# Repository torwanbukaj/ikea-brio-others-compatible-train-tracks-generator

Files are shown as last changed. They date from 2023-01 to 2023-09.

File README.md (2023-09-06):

# IKEA Lillabo- & BRIO- & others- compatible train tracks generator

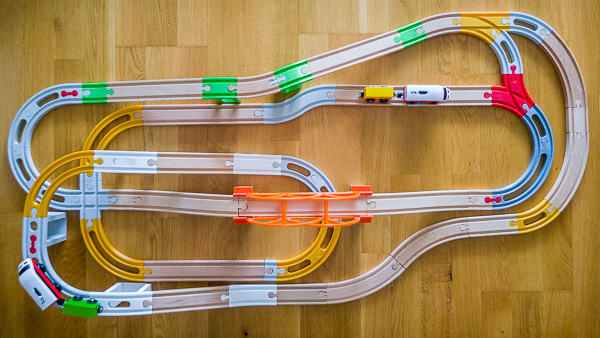
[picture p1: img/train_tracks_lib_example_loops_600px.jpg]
Train tracks loops


This work is licensed under a
[Creative Commons Attribution-NonCommercial-ShareAlike 4.0 International License][cc-by-nc-sa].

# Summary

Read this summary till the end before you print any part generated by this generator!

This repository can be used in two ways:
- just download, slice and 3D print provided STL files,
- generate your own models using provided OpenSCAD file (src/train_tracks_generator.scad), you can easily modify properties of your models as well as change common dimensions used by the generator (track width, height, plug & nest radius etc.).

The generator can so far be used to generate the following types of train tracks:
- short, low profile test track,
- straight tracks,
- arcs (track curves),
- bridges,
- switches,
- intersections,
- "snake" tracks,
- dog-bones (nest-to-nest connection),
- adapters between various train track systems (e.g., IKEA<>BRIO).

Dimensions of the inter-connectors (plugs & nests) are defined based on my own measurements and experiments. They are chosen in a way that connecting a wooden track with a 3D printed one creates a connection which is a little bit tighter than a standard wood-to-wood connection is. Connecting two 3D-printed parts should give a snug and sturdy connection (maintaining a minimal play to ease disconnecting). A play between the parts (wooden vs 3D printed) could be reduced even more but then connecting two 3D-printed parts together would not be possible anymore. Keep it in mind if you decide to play with the configuration parameters.

# Are various train track systems compatible with each other?

It depends on how much force you are willing to apply :) In general, the answer is: NOT, the most popular systems are incompatible. For instance, tracks from IKEA and BRIO do not fit to each other well. The general dimensions of the parts are similar but - for instance - fitting IKEA track plug (shorter) to BRIO track nest (longer) may be impossible without braking or damaging one of the parts. Even if you will manage to connect two incompatible parts, it may be very difficult to disconnect them.
There may be of course exceptions. I found out that J'adore system (sourced from Rossmann) is pretty compatible with BRIO.

Do you posses two or more various systems and want to connect them? With use of my generator, you can easily generate an adapter which will allow to connect two different systems together.

# IMPORTANT - my strong advice - print the tester at first!

Before printing any "bigger" part generated by this generator, I highly recommend to print a tester-track relevant to the system you use:

- file "train_tracks_ikea_tester.stl" (for IKEA Lillabo),
- file "train_tracks_brio_tester.stl" (for BRIO).

This is a short, 20mm-long, low-profile railway track which takes maximum a dozen minutes to print and requires only ~2g of filament. Test the printed part with your train tracks system. It will help you to asses if the dimensions of the parts (including track plug and nest) used by the generator fit dimensions of the tracks you own. If you posses genuine IKEA Lillabo or/and BRIO railway system/s, the generator default dimensions should be fine, nevertheless, when reading various comments for the similar projects on Internet, I found out that in some countries, dimensions of the tracks may differ a little bit from the commonly known. Default dimensions used in this library are tested on tracks available from IKEA (sourced from Germany & Poland), BRIO and J'adore (Rossmann). Please let me know about your test results in the comments and I will add more information to this description if necessary.  

Printed tester does not fit?
I tested multiple combinations of inter-connectors dimensions, so you should not experience any issues but if you do, do not worry, you can easily experiment and customize dimensions used by the generator to fit your system.

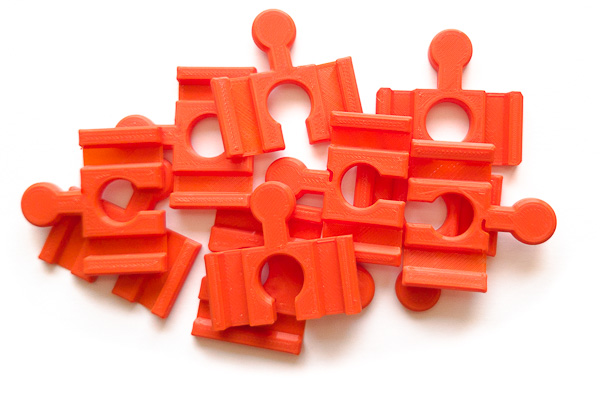
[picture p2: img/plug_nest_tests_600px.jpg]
Plug & nest tests


This is what I call a nest and a plug:

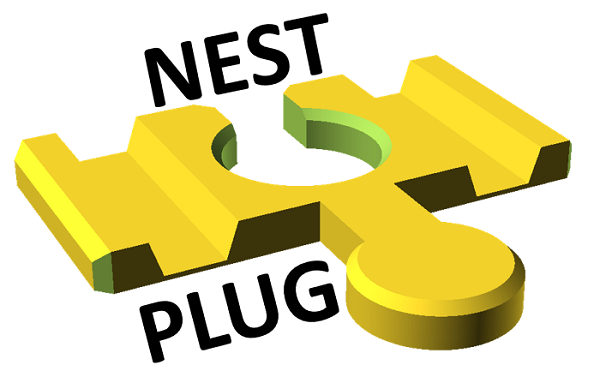
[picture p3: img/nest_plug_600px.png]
Plug & nest


If you want to change dimensions of a plug or a nest, locate these variables in the library and modify according to your needs (example values below are relevant for IKEA Lillabo):

	// Track Plug
	track_plug_radius = 6.25;
	track_plug_radius_ext = 6.5; // for a dog-bone with a springy plug
	track_plug_neck_width = 6.1;
	track_plug_neck_length = 11;
	
	// Track Nest
	track_nest_radius = 6.4;
	rack_nest_neck_width = 6.3;
	track_nest_neck_length = 11;

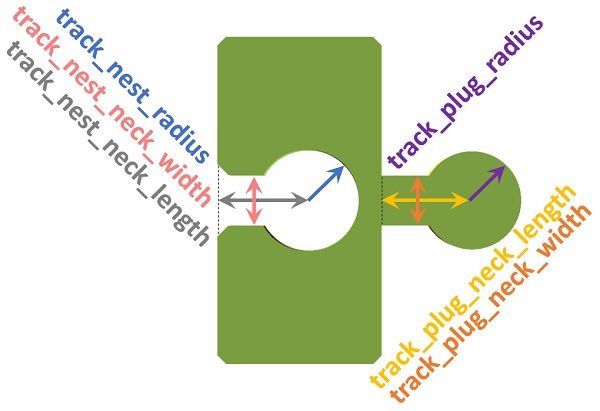
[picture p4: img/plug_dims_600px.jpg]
Plug dimensions


# "We want a bridge!" -> module generate_bridge(); 

This is actually how this story began. We had some IKEA Lillabo and J'adore wooden railway tracks at home but these were only basic parts which were useful for building nothing more than two traditional "2D" loops. One day I heard "We want a bridge!". IKEA is maybe not far away from us but when we want to go there, it's already a kind of trip to organize. And the "bridges" offer is not too impressive in IKEA, and our 3D printer stands in the next room, and there was willingness to improve OpenSCAD skills, so...the project was born.

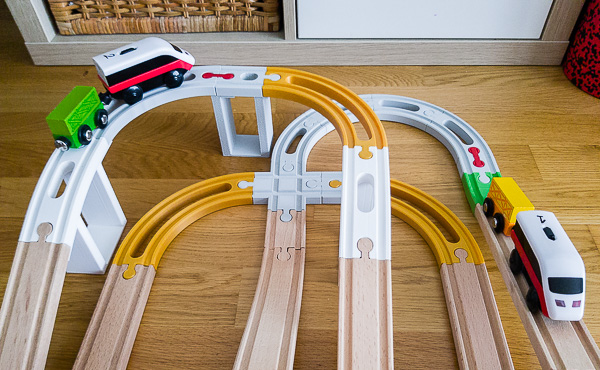
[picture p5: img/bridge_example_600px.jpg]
Example bridge


To build a full bridge, you will need minimum five parts: two "ground" and two "slope" parts,  plus so called a "dog-bone" when you are going to use straight connecting tracks in plug-nest configuration. The ground and slope parts have to be connected by a straight track of your choice. I highly recommend to use one of the standard straight tracks from an original IKEA Lillabo main or expansion set. I think it makes no sense really to print the simplest, commonly available parts.
You can easily extend the total length of the bridge by adding one or more "pillar" track parts.

OpenSCAD module to build a bridge is called "**generate_bridge();**" It takes a few parameters but the most important one is called *what_to_generate". It controls what the module generates. These are the possible values:
- 0 - generates a bridge overview and calculates what will be the height of the bridge,
- 1 - generates only a "ground" part,
- 2 - generates only a "slope" part,
- 3 - generates only a "pillar" part.

This is an example of a bridge overview:

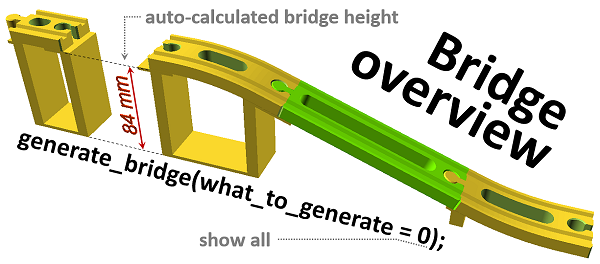
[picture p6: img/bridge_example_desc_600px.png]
Example bridge overview


You can generate a bridge without providing any further parameters. In such a case default values will be used:

	generate_bridge(what_to_generate = 0,
	bridge_angle = 14,
	slope_radius = 100',
	straight_part_l = 205,
	pillar_l = 50,
	cutout = true);

The picture below explains the bridge module parameters:

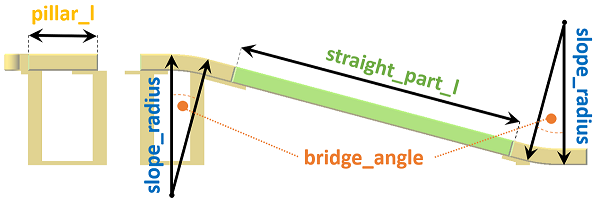
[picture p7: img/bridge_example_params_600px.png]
Bridge parameters


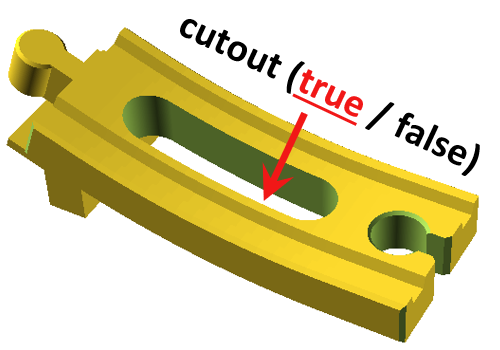
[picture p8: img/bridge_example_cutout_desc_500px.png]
Bridge part cutout description


To speed up printing of the bridge parts and to reduce amount of filament which has to be used for supports, I recommend to slice the parts in the following position (laying on a sidewall):

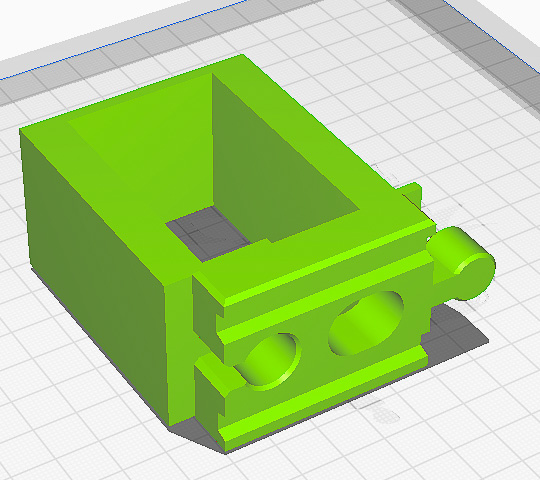
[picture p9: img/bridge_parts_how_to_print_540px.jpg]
Bridge parts - how to print


# Straight railway track -> module track();

Straight railway track is the simplest to generate. Just use **track();** module. You will find explanation of the available parameters on the pictures below:

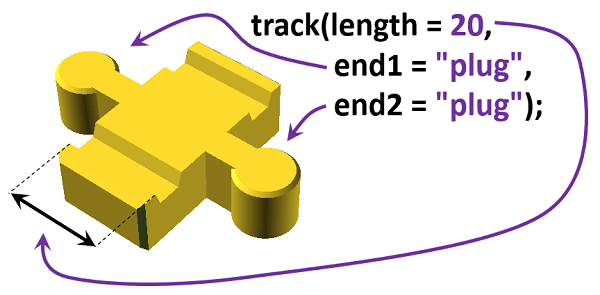
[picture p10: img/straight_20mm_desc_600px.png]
Straight railway track - Example 1

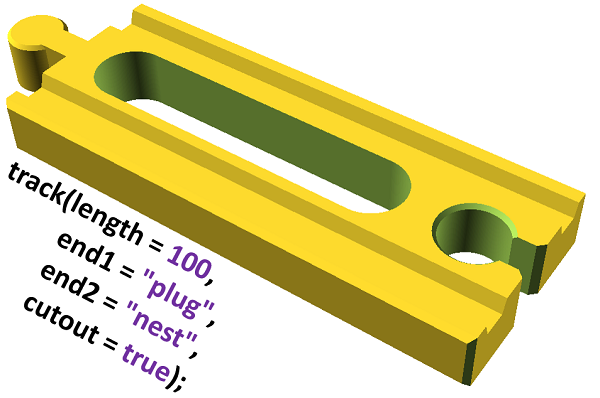
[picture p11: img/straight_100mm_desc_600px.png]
Straight railway track - Example 2


# Arcs -> module track_arc(); 

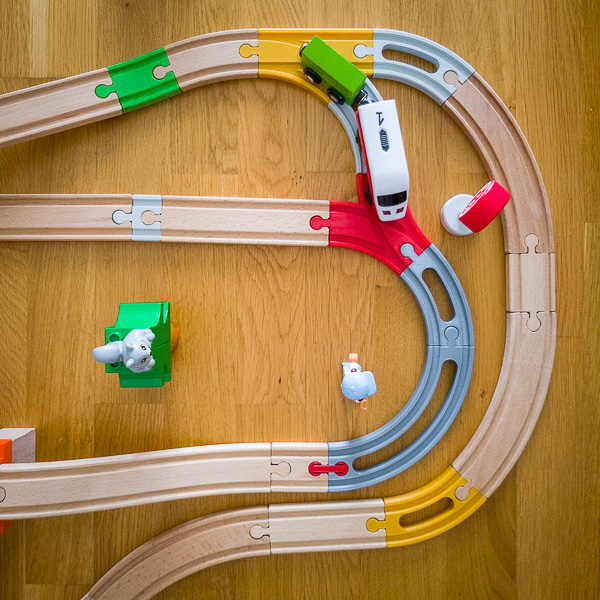
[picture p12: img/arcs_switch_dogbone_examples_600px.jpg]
Arcs examples


To generate an arc, use **track_arc()** module. You can define an ark angle, radius and configuration of its endings (plugs/nests). Positive angles will cause generating an arc which turns to the left and negative angles will force generation of an arc turning right. In addition, you can control if a part will be generated with a material-saving **cutout** or without it. Parameter **both_sides** allows to control if the part will have groves on both sides or only on the top side. This is important if you want to keep the part the most universal (flip it up -side-down and it will turn to the opposite side). 

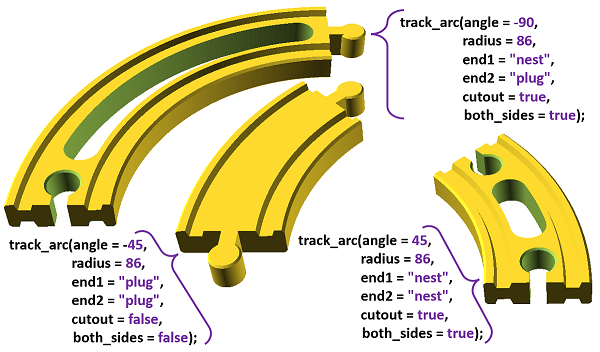
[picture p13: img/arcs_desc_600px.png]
Arc description


# Intersections -> module intersection(); 

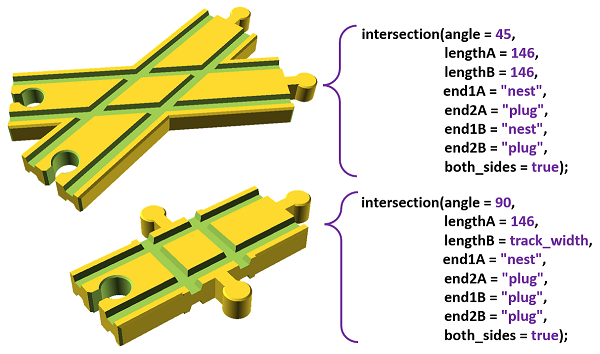
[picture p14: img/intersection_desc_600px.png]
Intersection description


# Switches -> module switch();

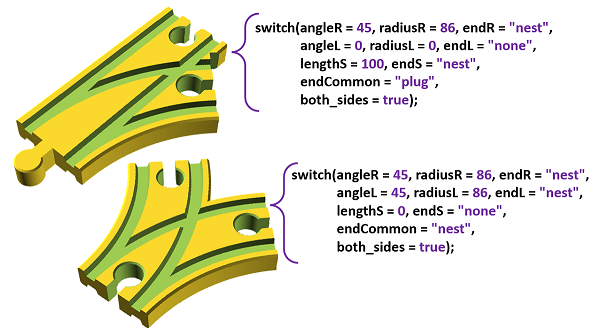
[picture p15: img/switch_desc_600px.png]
Switch description


# "Snake" track -> module snake_track();

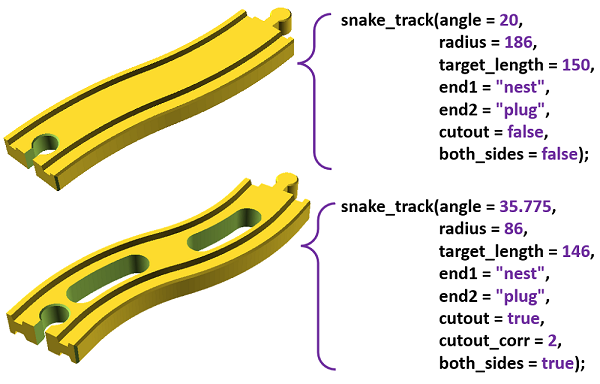
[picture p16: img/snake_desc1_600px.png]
Snake track description 1

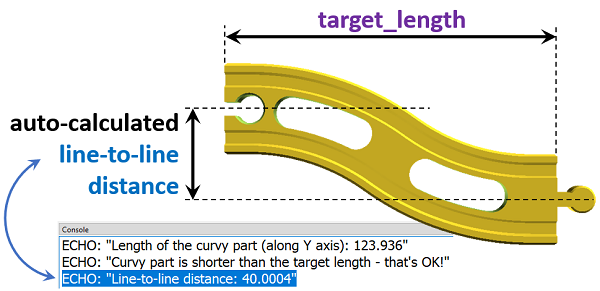
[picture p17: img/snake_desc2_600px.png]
Snake track description 2


# Dog-bone -> module track_dogbone(); 

A dog-bone is a part generated using additional parameter called **track_plug_radius_ext**. It should be always set to a little larger value than standard plug radius. When connecting two track parts facing each other with nests, you are interested in reducing lateral play. This is exactly why the dog-bone has slightly oversized "heads". Deep cutouts allow such plugs to be flexible and tightly fit to slightly "undersized" for them nests.

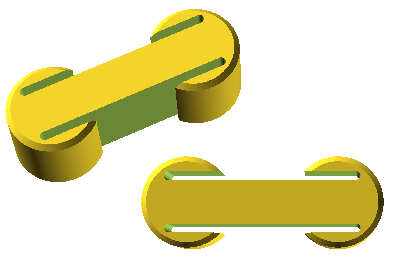
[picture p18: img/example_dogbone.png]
Dog-bone


# Adapters -> module tracks_adapter();

As mentioned in the summary above, some systems are just incompatible with each other (like IKEA and BRIO). This does not mean that you cannot use them together. I guess this incompatibility is just a standard method of locking us - customers - to a specific system. You can easily escape this game played by train tracks manufacturers by using dedicated adapters. Adaptation takes place only in the plug/nest areas (body of a whole adapter is always "common").

Generating an adapter is as easy as calling **tracks_adapter();** module with appropriate parameters (default values in the brackets):

	tracks_adapter(length = 30, nest = "B", plug = "I");

- length - total adapter length (without a plug), I recommend 30mm minimum,
- nest - here you have to define what is the "nest" system,
- plug - here you have to define what is the "plug" system.

So far, dimensions for two plug/nest systems are defined:
- IKEA Lillabo represented by the letter "I",
- BRIO represented by the letter "B".

Below you can find two examples of parts generated to connect IKEA and BRIO systems:

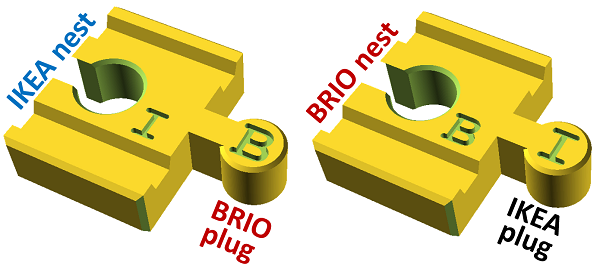
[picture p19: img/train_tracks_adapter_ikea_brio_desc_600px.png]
Adapters description

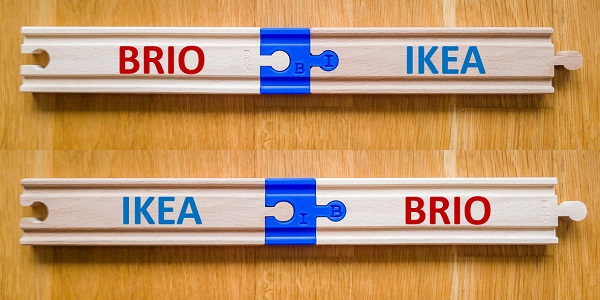
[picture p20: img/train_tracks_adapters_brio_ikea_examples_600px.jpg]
Example adapters


---
Shield: [][cc-by-nc-sa]

This work is licensed under a
[Creative Commons Attribution-NonCommercial-ShareAlike 4.0 International License][cc-by-nc-sa].

[][cc-by-nc-sa]

[cc-by-nc-sa]: http://creativecommons.org/licenses/by-nc-sa/4.0/
[cc-by-nc-sa-image]: https://licensebuttons.net/l/by-nc-sa/4.0/88x31.png
[cc-by-nc-sa-shield]: https://img.shields.io/badge/License-CC%20BY--NC--SA%204.0-lightgrey.svg

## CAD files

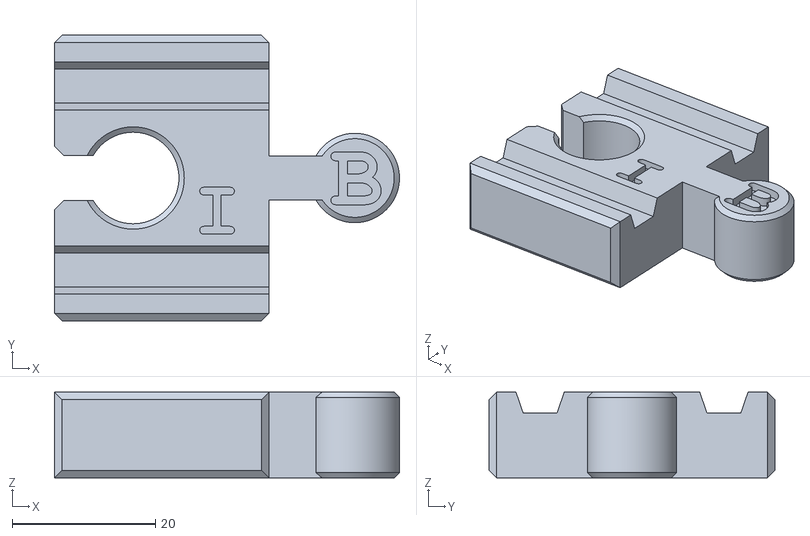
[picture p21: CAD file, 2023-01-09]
pre-generated_parts_stl/adapters/train_tracks_adapter_30mm_ikea-nest_brio-plug.stl
48.2 x 40.0 x 12.0

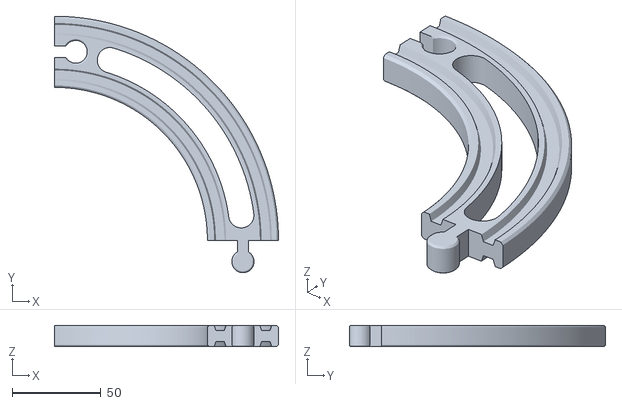
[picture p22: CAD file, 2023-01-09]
pre-generated_parts_stl/brio/train_tracks_brio_arc90deg_r86_b_NP.stl
126.0 x 144.2 x 12.0

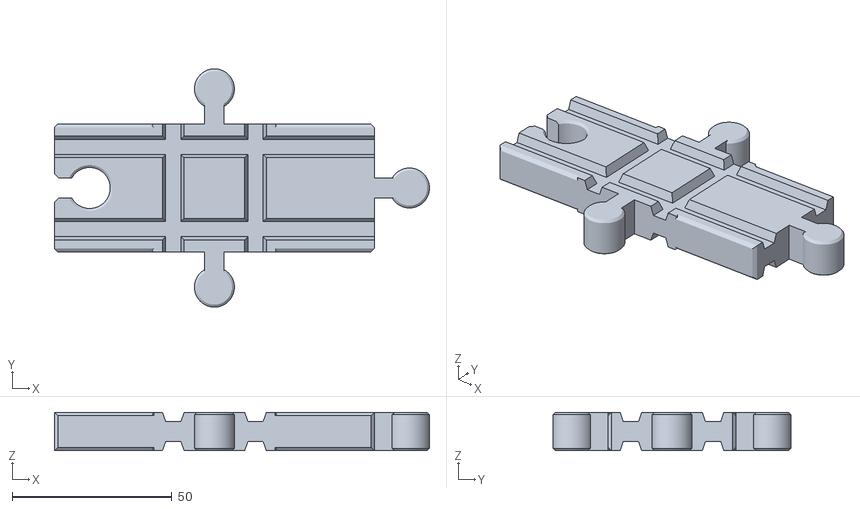
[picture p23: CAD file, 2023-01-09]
pre-generated_parts_stl/ikea/train_tracks_ikea_lillabo_intersect_90deg_100mmNP_40mmPP_b.stl
117.2 x 74.5 x 12.0

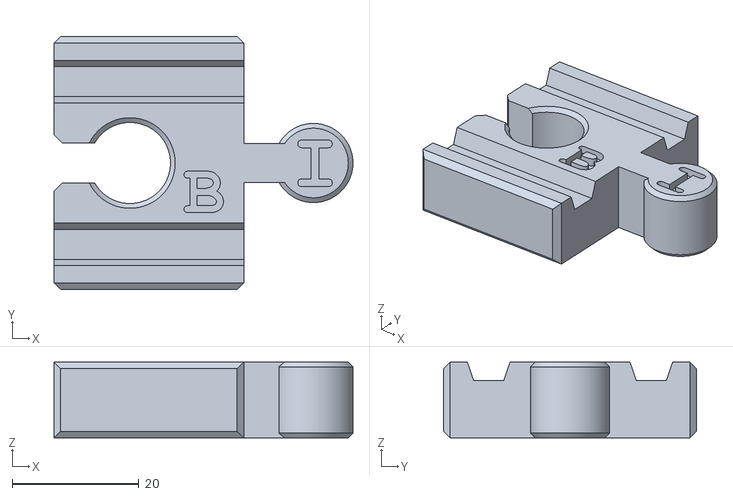
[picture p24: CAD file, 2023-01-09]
pre-generated_parts_stl/adapters/train_tracks_adapter_30mm_brio-nest_ikea-plug.stl
47.2 x 40.0 x 12.0

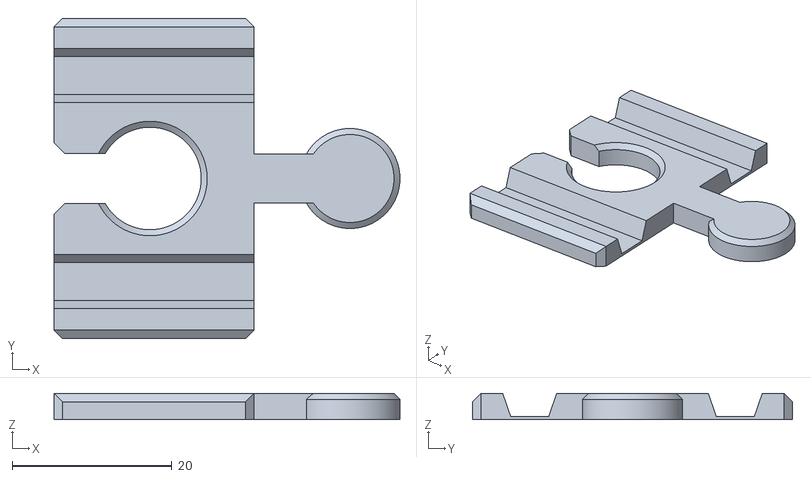
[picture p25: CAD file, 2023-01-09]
pre-generated_parts_stl/brio/train_tracks_brio_tester.stl
43.2 x 40.0 x 3.30

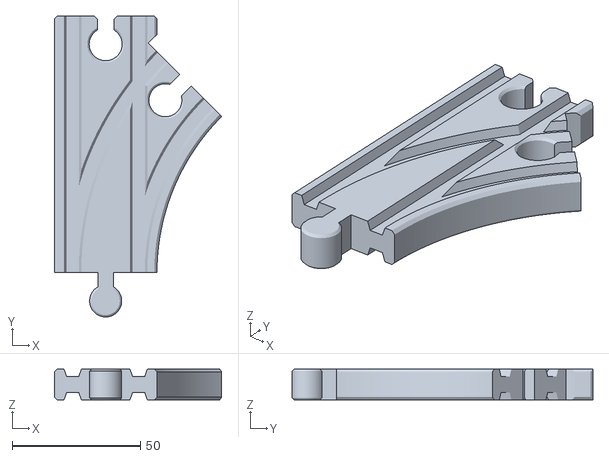
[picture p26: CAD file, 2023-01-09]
pre-generated_parts_stl/ikea/train_tracks_ikea_lillabo_switch_45deg_r86mmN_s100mmN_cP_b.stl
65.2 x 117.2 x 12.0

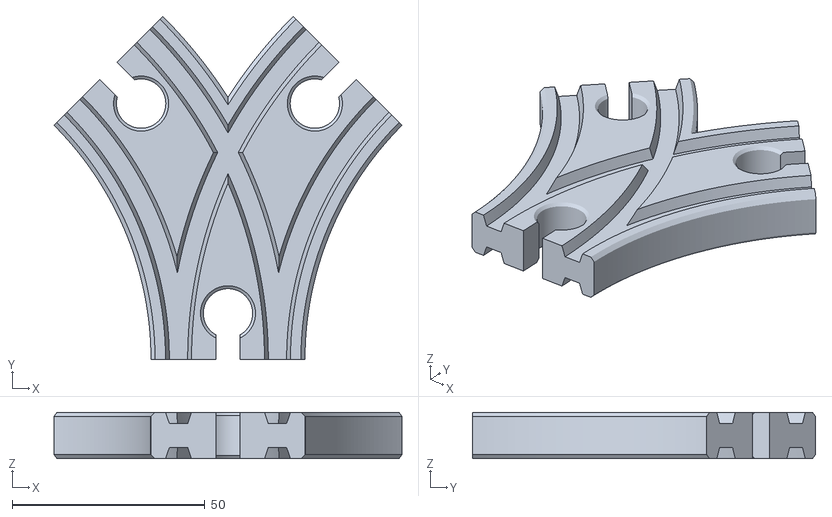
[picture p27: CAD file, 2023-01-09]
pre-generated_parts_stl/brio/train_tracks_brio_switch_l45deg_r86mmN_r45deg_r86mmN_cN_b.stl
90.4 x 89.1 x 12.0

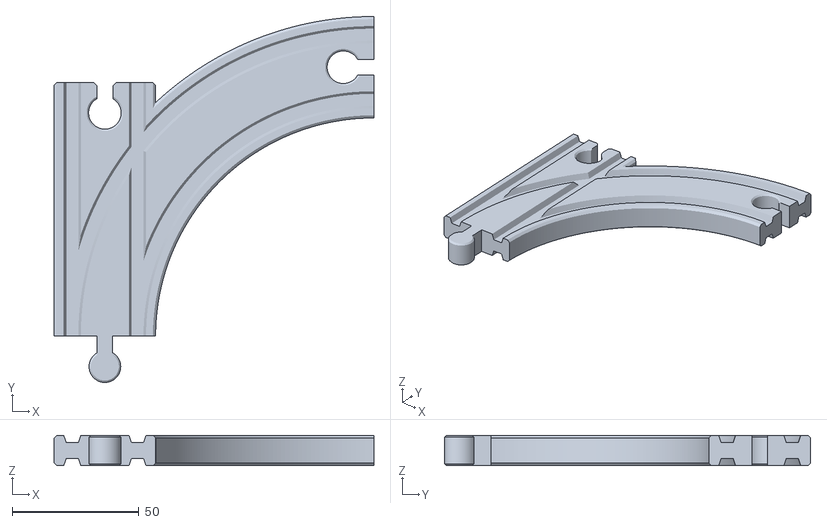
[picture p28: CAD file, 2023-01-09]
pre-generated_parts_stl/brio/train_tracks_brio_switch_90deg_r86mmN_s100mmN_cP_b.stl
126.0 x 144.2 x 12.0

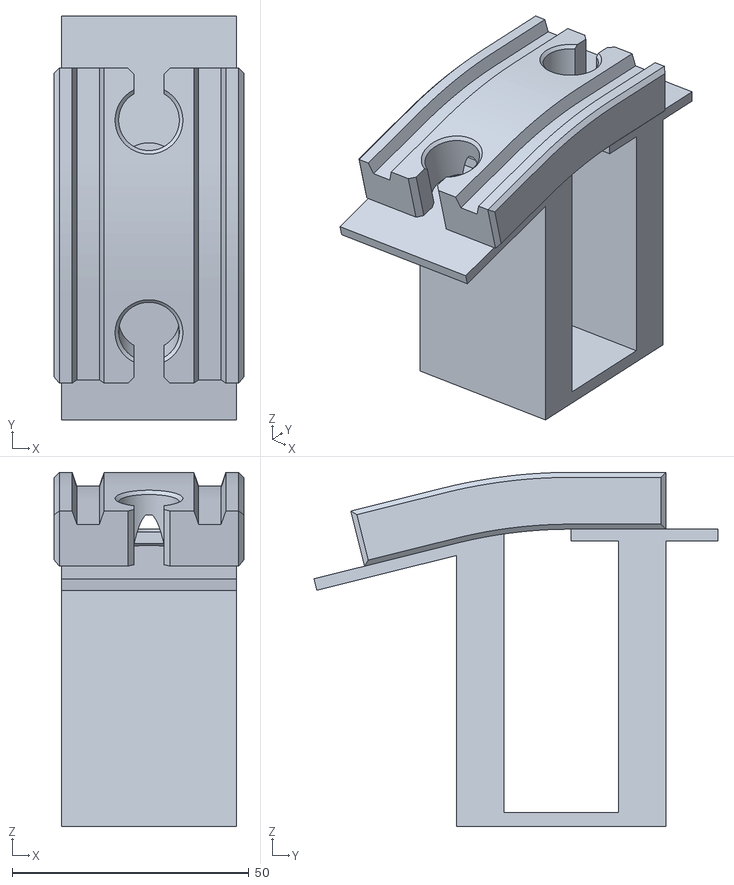
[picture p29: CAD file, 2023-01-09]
pre-generated_parts_stl/ikea/train_tracks_ikea_lillabo_bridge_slope_14deg_r100mm_s205mm_p50mm.stl
40.0 x 85.3 x 74.8

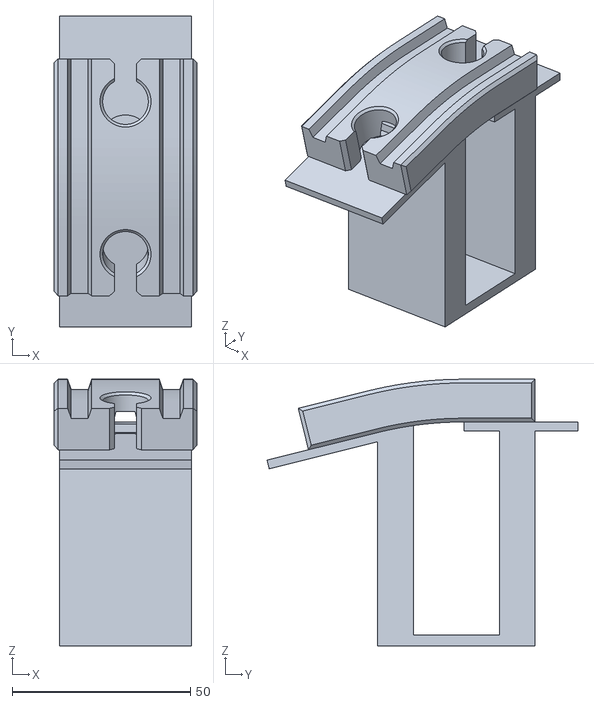
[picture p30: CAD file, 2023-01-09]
pre-generated_parts_stl/brio/train_tracks_brio_bridge_slope_14deg_r100mm_s205mm_p50mm.stl
40.0 x 87.2 x 74.8

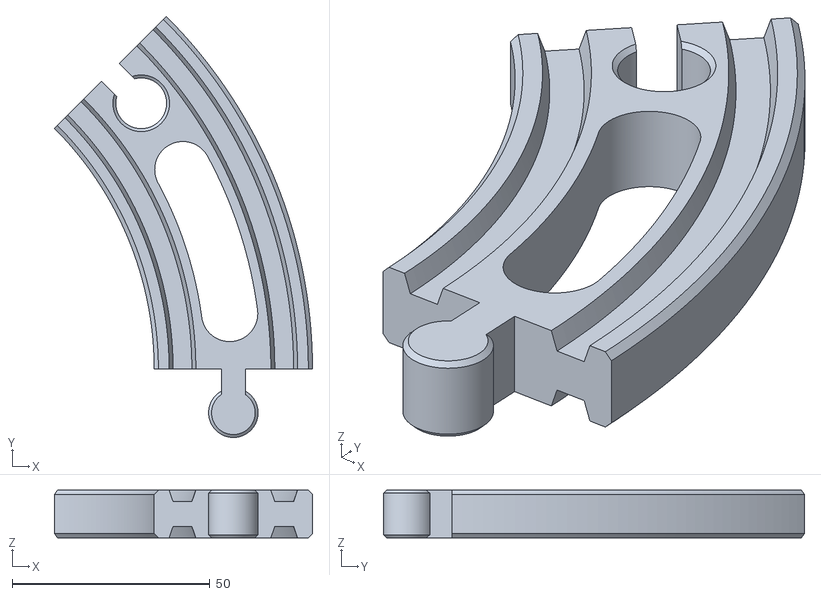
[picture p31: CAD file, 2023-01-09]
pre-generated_parts_stl/ikea/train_tracks_ikea_lillabo_arc45deg_r86mm_b_NP.stl
65.2 x 106.3 x 12.0

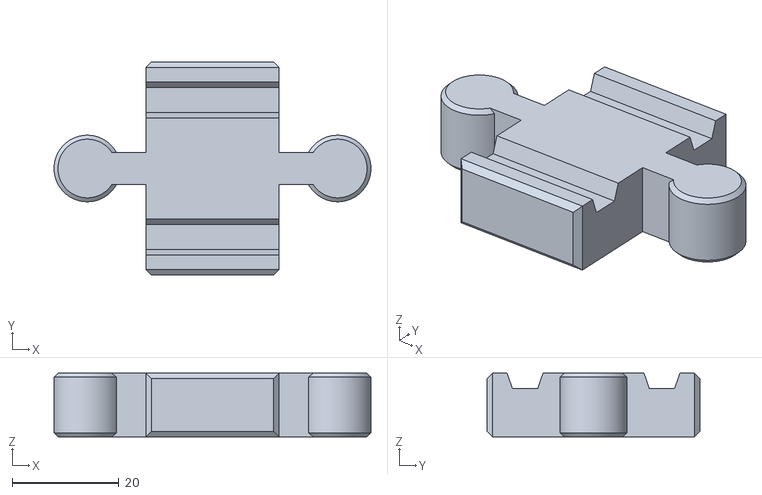
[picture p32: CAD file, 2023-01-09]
pre-generated_parts_stl/ikea/train_tracks_ikea_lillabo_straight25mm_PP.stl
59.5 x 40.0 x 12.0

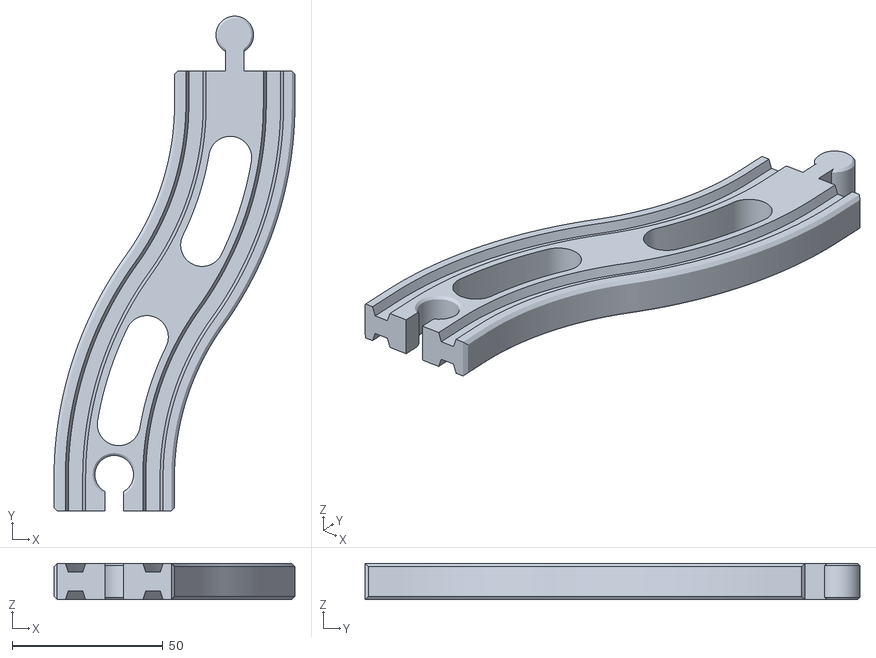
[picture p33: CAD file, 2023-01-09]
pre-generated_parts_stl/brio/train_tracks_brio_snake_35_775deg_r86mm_l146mm_NP_b.stl
80.0 x 164.3 x 12.0

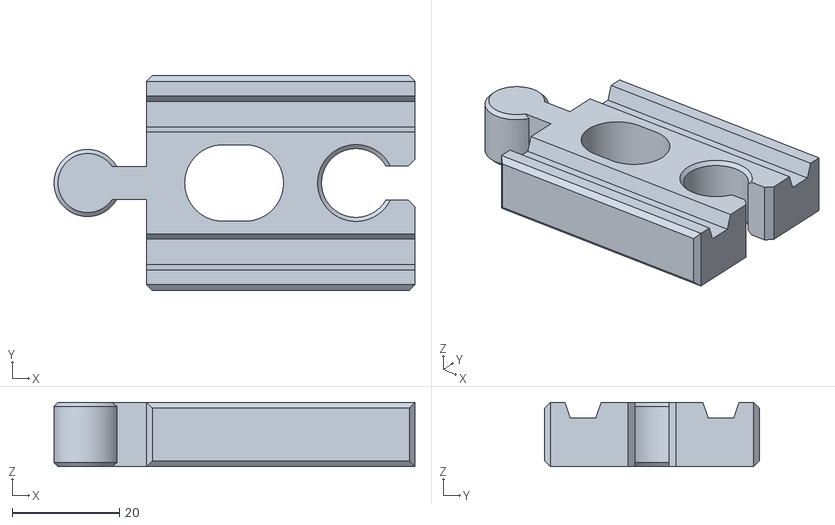
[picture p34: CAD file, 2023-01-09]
pre-generated_parts_stl/ikea/train_tracks_ikea_lillabo_straight50mm_NP.stl
67.2 x 40.0 x 12.0

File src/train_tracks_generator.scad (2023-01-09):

// Train tracks generator for IKEA Lillabo, Brio and others
//// by torwan @ January 8th, 2023

// Description / Hints:
// - See more details on https://www.thingiverse.com/thing:5598668
// - All dimensions in [mm].
// - Before printing any "bigger" part generated by this generator,
//   I highly recommend to print a tester-track relevant to the system
//   you posses. Use the "track_tester()" module to generate a tester.
// - To print STL file, render the object using F6 and save
//   an STL file using F7.
// - Standard lengths of the IKEA Lillabo straight tracks (without
//   a plug): 50mm, 100mm, 146mm, 205mm, 240mm.
// - Standard arcs in the IKEA Lillabo tracks family (original tracks
//   measured): 45deg + inner radius 185mm which gives U-turn inner
//   diameter 370mm, 22.5deg + inner radius 180mm which gives U-turn
//   inner diameter 360mmm.
// - Arc parameters used in J'adore system (sold e.g., by Rossmann):
//   45deg, inner radius 86mm, => U-turn inner diameter 172mm
// - Standard lengths of the Brio straight tracks (without a plug):
//   145mm.
// - $fn controls number of a circle fragments. I recommend to use
//   $fn = 300;, especially for larger arcs and bridge parts. Keep
//   in mind that the larger value of $fn, the longer rendering will
//   take, but also the smoother "roundy" parts of your tracks will
//   be. When tinkering around and playing with different parameters
//   values, I recommend using smaller $fn value unless you have rally
//   fast CPU/GPU PC configuration.

//$fn = 300;
$fn = 150;

// ### General track dimensions

// Track dimensions (based on original IKEA Lillabo and BRIO tracks).
// You should not change these values unless you are going to tune this
// generator to some really different system than the ones available
// commonly on the market.
track_width = 40;
track_height = 12;
track_well_depth = 2.9;
track_well_width_top = 6.75;
track_well_width_bottom = 4.75;
track_well_spacing = 25.7;
track_chamfer = 1.5;


// ### DO NOT CHANGE BELOW DEFINITIONS UNLESS IT IS REALLY NECESSARY
// ### (use the "general" variables to play with various dimensions instead)

// Track Plug IKEA Lillabo (do not change)
ikea_track_plug_radius = 6.25;      // 6.25
ikea_track_plug_radius_ext = 6.5;   // 6.5 for a dog-bone with springy plug
ikea_track_plug_neck_width = 6.1;   // 6.1
ikea_track_plug_neck_length = 11;   // 11
ikea_track_plug_txt = "I";

// Track Nest IKEA Lillabo (do not change)
ikea_track_nest_radius = 6.4;      // 6.4
ikea_track_nest_neck_width = 6.3;  // 6.3
ikea_track_nest_neck_length = 11;  // 11
ikea_track_nest_txt = "I";

// Track Plug Brio (do not change)
brio_track_plug_radius = 6.25;     // 6.25
brio_track_plug_radius_ext = 6.5;  // 6.5 for a dog-bone with springy plug
brio_track_plug_neck_width = 6.1;  // 6.1
brio_track_plug_neck_length = 12;  // 12
brio_track_plug_txt = "B";

// Track Nest Brio (do not change)
brio_track_nest_radius = 6.4;      // 6.4
brio_track_nest_neck_width = 6.3;  // 6.3
brio_track_nest_neck_length = 12;  // 12
brio_track_nest_txt = "B";

// Bridge components (do not change)
bridge_pillar_depth = 10;
slope_straight_nest_length = 20; //length of the straight ending (with nest)
slope_straight_plug_length = 10; //length of the straight ending (without plug)

// Helpers (do not change)
tr_wl_w_stick_out = (track_well_width_top-track_well_width_bottom)/2;
tr_co_w = 0.75 * (track_well_spacing-track_well_width_top); // track cutout width
cc = 0.001;
switch_cut_ext = 1; 

// ### USE BELOW VARIABLES TO CHOOSE YOUR TARGET SYSTEM
// ### Below variables are used by majority of modules in this library.
// ### Feel free to define your own values here instead of using
// ### pre-defined parameters for specific systems.
// ### For example: track_plug_radius = 6.45;

// Track Plug - choose your system here or define your own values
track_plug_radius = ikea_track_plug_radius;
track_plug_radius_ext = ikea_track_plug_radius_ext;
track_plug_neck_width = ikea_track_plug_neck_width;
track_plug_neck_length = ikea_track_plug_neck_length;
track_plug_txt = ikea_track_plug_txt;

// Track Nest  - choose your system here or define your own values
track_nest_radius = ikea_track_nest_radius;
track_nest_neck_width = ikea_track_nest_neck_width;
track_nest_neck_length = ikea_track_nest_neck_length;
track_nest_txt = ikea_track_nest_txt;


// ### TESTING / GENERATION AREA / EXAMPLES
// ### Below I have provided many examples of how to call a generator module.
// ### They should help to learn quickly how to generate a desired model.
// ### When trying different module, always remember to comment back
// ### a previously used one :)
// ### If you have any doubts regarding some parameters, see detailed description
// ### provided in the front of each module definition.

// ---------------------------------
//TRACK TESTER
track_tester();

// ---------------------------------
// TRACKS ADAPTER
//tracks_adapter(length = 30, nest = "B", plug = "I");
//tracks_adapter(length = 30, nest = "I", plug = "B");

// ---------------------------------
// STRAIGHT track examples
/*
track(length = 100,
      end1 = "plug",
      end2 = "nest",
      cutout = true);
*/

/*
track(length = 25,
      cutout = true,
      end1 = "plug",
      end2 = "nest",
      part_chamfers = true,
      grooves = true);
*/

/*
track(length = 50,
      cutout = true,
      end1 = "plug",
      end2 = "nest",
      part_chamfers = true,
      grooves = true);
*/

// ---------------------------------
// ARC track examples
//track_arc();
//track_arc(angle = 90, radius = 86, both_sides = true);
//track_arc(angle = 45, radius = 185, both_sides = true);
//track_arc(angle = 22.5, radius = 180);
//track_arc(angle = -45, radius = 185, cutout = false, both_sides = false);

/*
track_arc(angle = -90,
          radius = 86,
          end1 = "nest",
          end2 = "plug",
          grooves = true,
          both_sides = true,
          cutout = true,
          cutout_corr = 0,
          part_chamfers = true);
*/

/*
track_arc(angle = -45,
          radius = 86,
          end1 = "nest",
          end2 = "plug",
          grooves = true,
          both_sides = true,
          cutout = true,
          cutout_corr = 0,
          part_chamfers = true);
*/
/*
track_arc(angle = 45,
          radius = 86,
          end1 = "nest",
          end2 = "nest",
          grooves = true,
          both_sides = true,
          cutout = true,
          cutout_corr = 0,
          part_chamfers = true);
*/
/*
track_arc(angle = -45,
          radius = 185,
          end1 = "nest",
          end2 = "nest",
          grooves = true,
          both_sides = false,
          cutout = true,
          cutout_corr = 0,
          part_chamfers = true);
*/

/*
track_arc(radius = 86, angle = -90,
                 end1 = "plug", end2 = "plug",
                 grooves = true,
                 both_sides = true,
                 cutout = true,
                 cutout_corr = 15,
                 part_chamfers = true);
*/

// ---------------------------------
// DOGBONE
//track_dogbone();

// ---------------------------------
// INTERSECTION examples

/*
intersection(angle = 90,
             lengthA = 75, // 75mm is too short for Brio
             lengthB = 75, // 75mm is too short for Brio
             both_sides = true);
*/
/*
intersection(angle = 45,
             lengthA = 146,
             lengthB = 146,
             end1A = "nest",
             end2A = "plug",
             end1B = "nest",
             end2B = "plug",
             both_sides = true);
*/
/*
intersection(angle = 90,
             lengthA = 100,
             lengthB = track_width,
             end1A = "nest",
             end2A = "plug",
             end1B = "plug",
             end2B = "plug",
             both_sides = true);
*/


// ---------------------------------
// BRIDGE set examples
//  - what_to_generate - controls what is generated by the module,
//    allowed values:
//      -- 0 (zero) - shows a bridge overview with calculation of
//         the bridge height
//      -- 1 - shows ONLY a bridge ground part
//      -- 2 - shows ONLY a bridge slope (upper) part
//      -- 3 - shows ONLY a bridge pillar part


// Showcase 15 degrees, radius 100mm, 205mm straight part, 50mm pillar length:
/*
generate_bridge(what_to_generate = 0,
                bridge_angle = 15,
                slope_radius = 100,
                straight_part_l = 205,
                pillar_l = 50,
                cutout = true);
*/

// Showcase 20 degrees, radius 200mm, 146mm straight part, 50mm pillar length:
/*
generate_bridge(what_to_generate = 1,
                bridge_angle = 20,
                slope_radius = 200,
                straight_part_l = 146,
                pillar_l = 50,
                cutout = true);
*/

// Showcase 14 degrees, radius 100mm, 205mm straight part, 50mm pillar length:
//generate_bridge(what_to_generate = 0);
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

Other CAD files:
pre-generated_parts_stl/ikea/train_tracks_ikea_lillabo_arc90deg_r86mm_b_NP.stl
pre-generated_parts_stl/brio/train_tracks_brio_arc45deg_r86_b_NP.stl
pre-generated_parts_stl/brio/train_tracks_brio_intersect_90deg_100mmNP_40mmPP_b.stl
pre-generated_parts_stl/ikea/train_tracks_ikea_tester.stl
pre-generated_parts_stl/brio/train_tracks_brio_bridge_ground_14deg_r100mm_s205mm_p50mm.stl
pre-generated_parts_stl/brio/train_tracks_brio_bridge_pillar_14deg_r100mm_s205mm_p50mm.stl
pre-generated_parts_stl/brio/train_tracks_brio_dogbone65.stl
pre-generated_parts_stl/brio/train_tracks_brio_intersect_90deg_100mmNP_100mmNP_b.stl
pre-generated_parts_stl/brio/train_tracks_brio_straight100mm_NP.stl
pre-generated_parts_stl/brio/train_tracks_brio_straight25mm_NP.stl
pre-generated_parts_stl/brio/train_tracks_brio_straight25mm_PP.stl
pre-generated_parts_stl/brio/train_tracks_brio_straight50mm_NP.stl
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

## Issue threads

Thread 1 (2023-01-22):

Thanks for this tool :) Pillar vs track width

manuelhilgert, 2023-01-22:
Hi, thanks for this great tool - i have a suggestion to make it even better:

It would make the bridge parts much cleaner (no support for the pillar, no steps on the other site because it's not 100% straight) if the pillar were the same width as the track

Greetings from Germany
Manuel

torwanbukaj, 2023-05-28:
Hi, thanks for the positive feedback and sorry for the late response, I somehow overlooked this comment or Github failed to notify me, don't know why.

I have to admit I somehow knew that some users will not like that it is required to use support for the pillars of the bridge parts. It would require a little bit more of tinkering how to solve it to keep the design looking good and to preserve nice champers at majority of edges. And chamfers were on my priority list to make it pretty save to touch for kids. Without chamfers, the edges could be too sharp.

I also suffered from the same pain you implicitly mentioned but finally solved it by using FIberlogy filament which gives me great printing quality and very good breakout experience if it comes to printed supports. I have to say it really depends on a filament type and vendor how easily a support can be broken off from a part. I highly recommend to use scalpel blades to clean the parts from residues coming from the supports.

Anyway, the hint to make the bridge parts design better, to get rid of supports for the pillars is very good, I just have to find some time one day to push the project beyond the initial version :)

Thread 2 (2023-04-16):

[BRIO] Plug and Neck Diameter Variations

tobiasschuerg, 2023-04-16:
First: thanks for this fantastic generator!

After printing several switches which called themselves BRIO compatible (but were not) I now actually manages to print something that fits well.

It's intriguing and amusing that something as seemingly simple as a wooden railway can have so many incompatibilities, even within the same brand.

Our Brio track, which is approximately 5 years old, has a plug diameter of `11.5` and a neck diameter of `12.5`.

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

The default neck value for Brio works well, but the default plug size is too large, in my case. To improve compatibility and make the tracks fit out of the box, it might be beneficial to gather different sizes for each brand and establish an all-encompassing default set per brand. This way, users can achieve better fitting prints without having to adjust settings manually. Hopefully.

torwanbukaj, 2023-05-28:
Thanks for the positive feedback!

I can tell you that our pretty new IKEA set has a max difference between plug and nest diameters above 1.26mm and min ~1mm. I have to confess I spend some hours measuring dozens of tracks to get some grip on what's going on with these dimensions. I have to say it is quite difficult to find the sweet spot, especially when you have tracks from different "generations". When I thought I found the sweet spot, I tried to print some parts and...had to add some correction factors to make it fit better. I guess this whole topic may be also dependent on a filament is used, a 3D printer calibration etc. This is why I proposed some "default" dimensions but simultaneously I highly recommend to print a tester before printing some bigger parts. It is what it is, I think finding universal dimensions is - unfortunately - impossible.

Closed 2023-05-28.

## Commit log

2023-01-09 First upload of the source OpenSCAD file and pre-generated STL files.
    [train_tracks_adapter_30mm_brio-nest_ikea-plug.stl, train_tracks_adapter_30mm_ikea-nest_brio-plug.stl, train_tracks_brio_arc45deg_r86_b_NP.stl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]
2023-01-09 Readme.md update - intersections, switches, snake tracks

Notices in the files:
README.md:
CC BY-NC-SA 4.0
